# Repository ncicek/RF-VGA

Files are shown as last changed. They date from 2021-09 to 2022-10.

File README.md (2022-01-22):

# RF-VGA
A handy RF amplifier/attenuator tool for the lab. Based on a Hittite HMC625B.

- Frequency: 50MHz to 4GHz (see response plots below for roll off)
- Approximate gain / attenuation range: -10dB to +20dB
- Max input power: 11dBm
- Max output power: 16dBm (1dB compression point)

# Render:
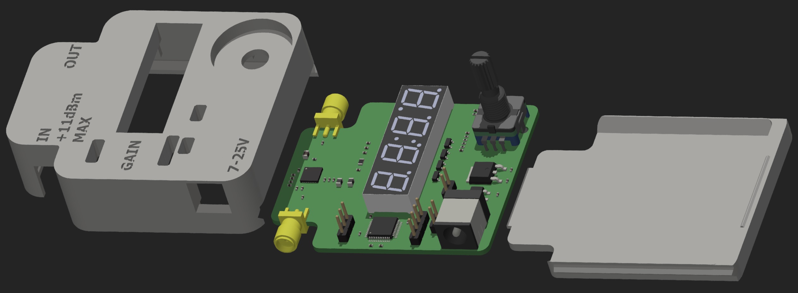
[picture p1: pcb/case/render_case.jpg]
Photo of the RF-VGA unit


# Board photo:
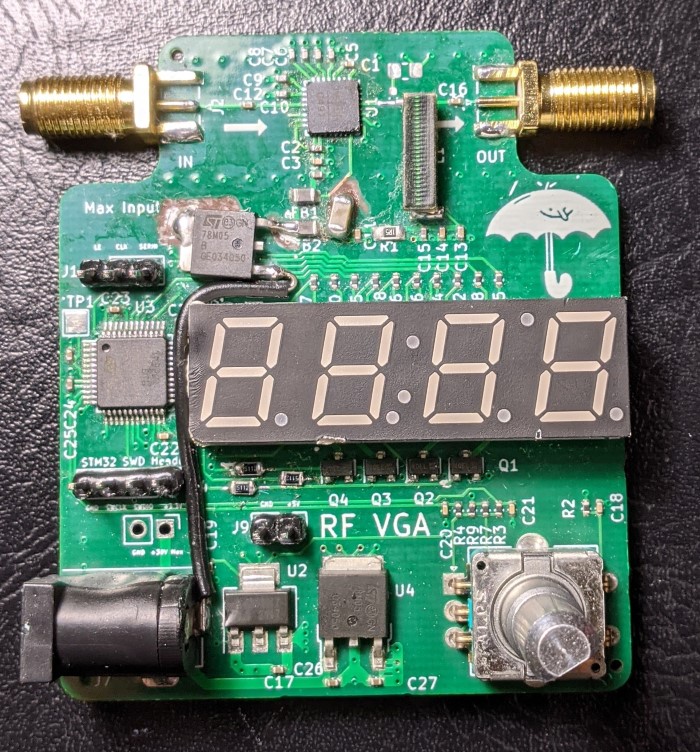
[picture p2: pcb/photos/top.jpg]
Photo of the RF-VGA board


# VNA characterization results:

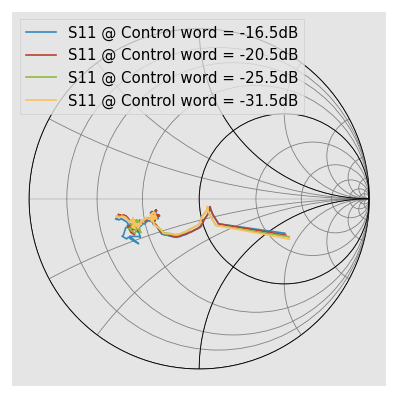
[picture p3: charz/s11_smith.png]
S11 Smith Chart


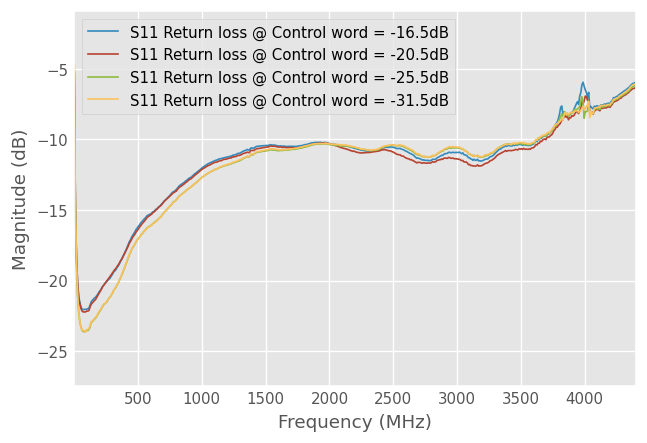
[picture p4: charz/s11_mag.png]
S11 Mag Chart

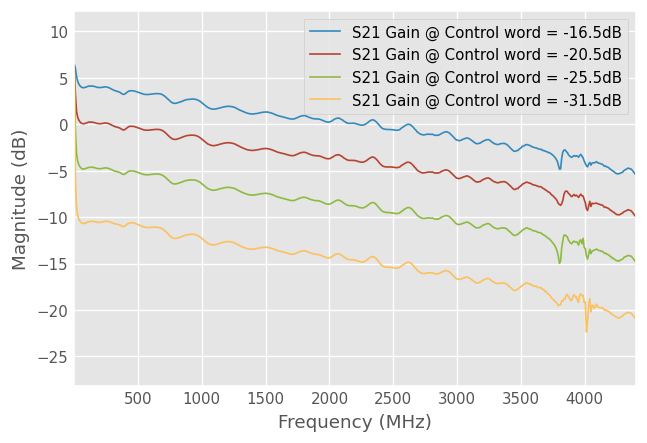
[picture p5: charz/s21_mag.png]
S21 Mag Chart


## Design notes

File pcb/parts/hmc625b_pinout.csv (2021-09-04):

HMC625B
Pin | Type | Name | Side
1 | input | AMPIN | left
29 | output | AMPOUT | right
2 | power | GND | bottom
3 | power | GND | bottom
13 | power | GND | bottom
28 | power | GND | bottom
30 | power | GND | bottom
31 | power | GND | bottom
32 | power | GND | bottom
4 | input | ATTOUT | left
12 | output | ATTIN | right
5 | input | AGC1 | bottom
6 | input | AGC2 | bottom
7 | input | AGC3 | bottom
8 | input | AGC4 | bottom
9 | input | AGC5 | bottom
10 | input | AGC6 | bottom
11 | input | GND | bottom
14 | output | SEROUT | right
15 | input | PUP2 | left
16 | input | PUP1 | left
18 | input | D5 | left
19 | input | D4 | left
20 | input | D3 | left
21 | input | D2 | left
22 | input | D1 | left
23 | input | D0 | left
24 | input | P/S | left
25 | input | CLK | left
26 | input | SERIN | left
27 | input | LE | left
17 | power | VDD | top

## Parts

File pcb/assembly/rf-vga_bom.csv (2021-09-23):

Comment | Designator | Footprint | LCSC
0.1u | C1,C12,C16,C22,C23,C24,C25,C28 | Capacitor_SMD:C_0402_1005Metric | C1525
2.2u | C13 | Capacitor_SMD:C_0402_1005Metric | C23733
0.1n | C2,C15 | Capacitor_SMD:C_0402_1005Metric | C1546
10n | C18,C20,C21 | Capacitor_SMD:C_0402_1005Metric | C15195
1n | C3,C11,C14 | Capacitor_SMD:C_0402_1005Metric | C1523
1u | C4,C17,C19,C26,C27 | Capacitor_SMD:C_0402_1005Metric | C52923
330p | C5,C6,C7,C8,C9,C10 | Capacitor_SMD:C_0402_1005Metric | C13533
TDCG1060M | DS1 | parts:DISPLAY_TDCG1060M
GZ2012D601TF | FB1,FB2 | Inductor_SMD:L_0805_2012Metric | C1017
TEST CONNECTOR | J1 | Connector_PinHeader_2.54mm:PinHeader_1x03_P2.54mm_Vertical
Input | J2 | parts:SMA_Samtec_SMA-J-P-X-ST-EM1_EdgeMount_withSTEP
Output | J3 | parts:SMA_Samtec_SMA-J-P-X-ST-EM1_EdgeMount_withSTEP
SWD Programming Header | J4 | Connector_PinHeader_2.54mm:PinHeader_1x04_P2.54mm_Vertical
Conn_02x04_Odd_Even | J5 | Connector_PinHeader_2.54mm:PinHeader_2x04_P2.54mm_Vertical
Barrel_Jack_Switch | J7 | Connector_BarrelJack:BarrelJack_Horizontal
30V input | J8 | Connector_PinHeader_2.54mm:PinHeader_1x02_P2.54mm_Vertical
5V input bypass | J9 | Connector_PinHeader_2.54mm:PinHeader_1x02_P2.54mm_Vertical
3.5u | L1 | 4310LC:4310LC
2N7002 | Q1,Q2,Q3,Q4 | Package_TO_SOT_SMD:SOT-23 | C20917
1.8 | R1 | Resistor_SMD:R_0402_1005Metric
10k | R2,R3,R4,R7,R9 | Resistor_SMD:R_0402_1005Metric | C25744
82 | R5,R6,R8,R10,R12,R14,R15,R16,R17,R18 | Resistor_SMD:R_0402_1005Metric | C25076
Rotary_Encoder_Switch | SW1 | Rotary_Encoder:RotaryEncoder_Alps_EC11E-Switch_Vertical_H20mm_CircularMountingHoles
TestPoint | TP1 | TestPoint:TestPoint_Pad_2.0x2.0mm
HMC625B | U1 | Package_DFN_QFN:QFN-32-1EP_5x5mm_P0.5mm_EP3.45x3.45mm_ThermalVias
LM1117-3.3 | U2 | Package_TO_SOT_SMD:SOT-223-3_TabPin2 | C6186
STM32L010C6 | U3 | Package_QFP:LQFP-48_7x7mm_P0.5mm | C2802165
LM78M05_TO252 | U4 | Package_TO_SOT_SMD:TO-252-2 | C58069

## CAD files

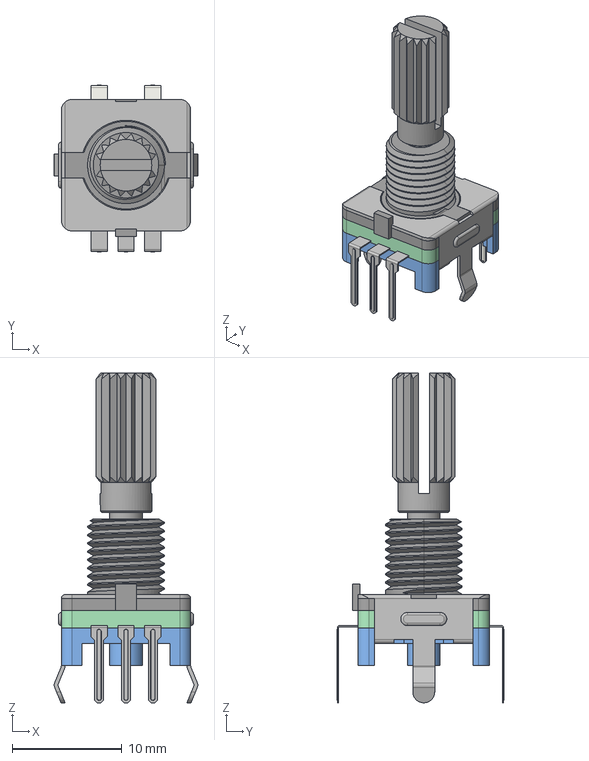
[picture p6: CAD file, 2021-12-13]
pcb/parts/EC11_Rotary_Encoder_Switched.step
13.1 x 15.3 x 30.1 mm

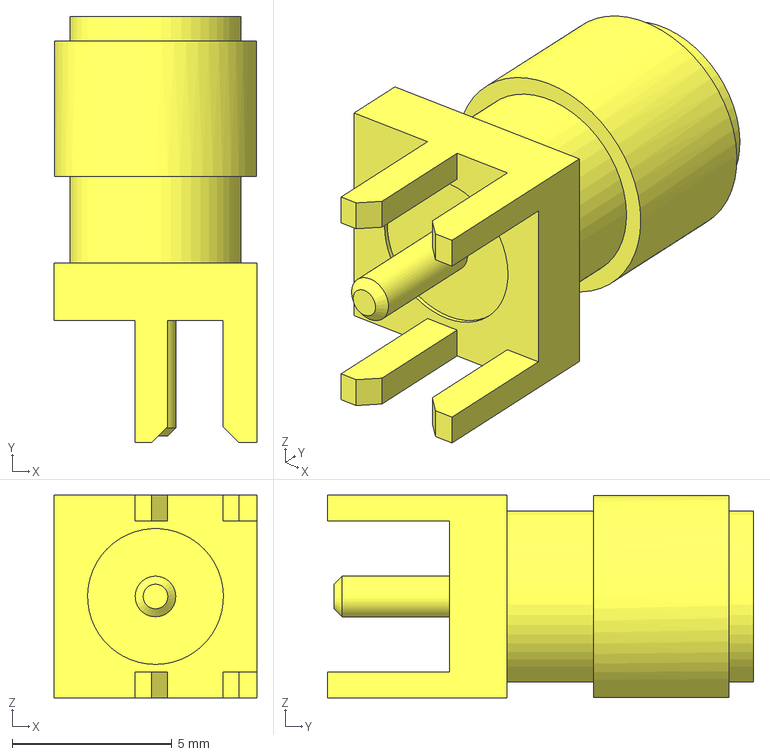
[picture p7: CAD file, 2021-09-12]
pcb/parts/SMA-J-P-H-ST-EM1--3DModel-STEP-46669.STEP
6.35 x 13.3 x 6.35 mm

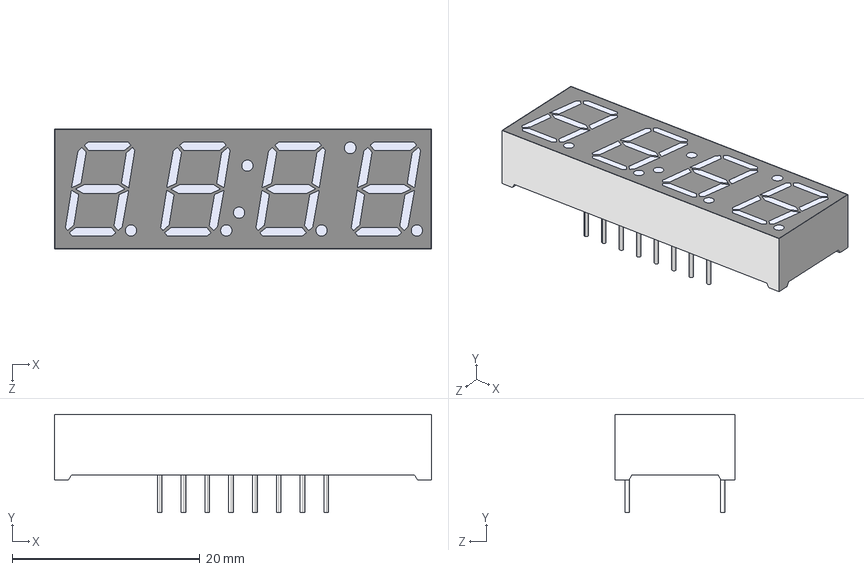
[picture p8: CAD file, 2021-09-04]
pcb/parts/TDCG1060M.step
40.2 x 10.5 x 12.8 mm

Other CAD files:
pcb/case/BarrelJack_CUI_PJ-063AH_Horizontal.iam
pcb/case/COMPOUND.ipt
pcb/case/COMPOUND_1.ipt
pcb/case/COMPOUND_2.ipt
pcb/case/COMPOUND_3.ipt
pcb/case/C_0402_1005Metric.iam
pcb/case/C_0805_2012Metric.iam
pcb/case/EC11_Rotary_Encoder_Switched.iam
pcb/case/LQFP-48_7x7mm_P0.5mm.iam
pcb/case/L_0402_1005Metric.iam
pcb/case/L_0805_2012Metric.iam
pcb/case/PinHeader_1x02_P2.54mm_Vertical.iam
pcb/case/PinHeader_1x03_P2.54mm_Vertical.iam
pcb/case/PinHeader_1x04_P2.54mm_Vertical.iam
pcb/case/PinHeader_2x04_P2.54mm_Vertical.iam
pcb/case/QFN-32-1EP_5x5mm_P0.5mm_EP3.45x3.45mm.iam
pcb/case/R_0402_1005Metric.iam
pcb/case/R_0805_2012Metric.iam
pcb/case/SMA-J-P-H-ST-EM1--3DModel-STEP-46669.iam
pcb/case/SOLID.ipt
pcb/case/SOLID_1.ipt
pcb/case/SOLID_10.ipt
pcb/case/SOLID_11.ipt
pcb/case/SOLID_12.ipt
pcb/case/SOLID_13.ipt
pcb/case/SOLID_14.ipt
pcb/case/SOLID_15.ipt
pcb/case/SOLID_2.ipt
pcb/case/SOLID_3.ipt
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

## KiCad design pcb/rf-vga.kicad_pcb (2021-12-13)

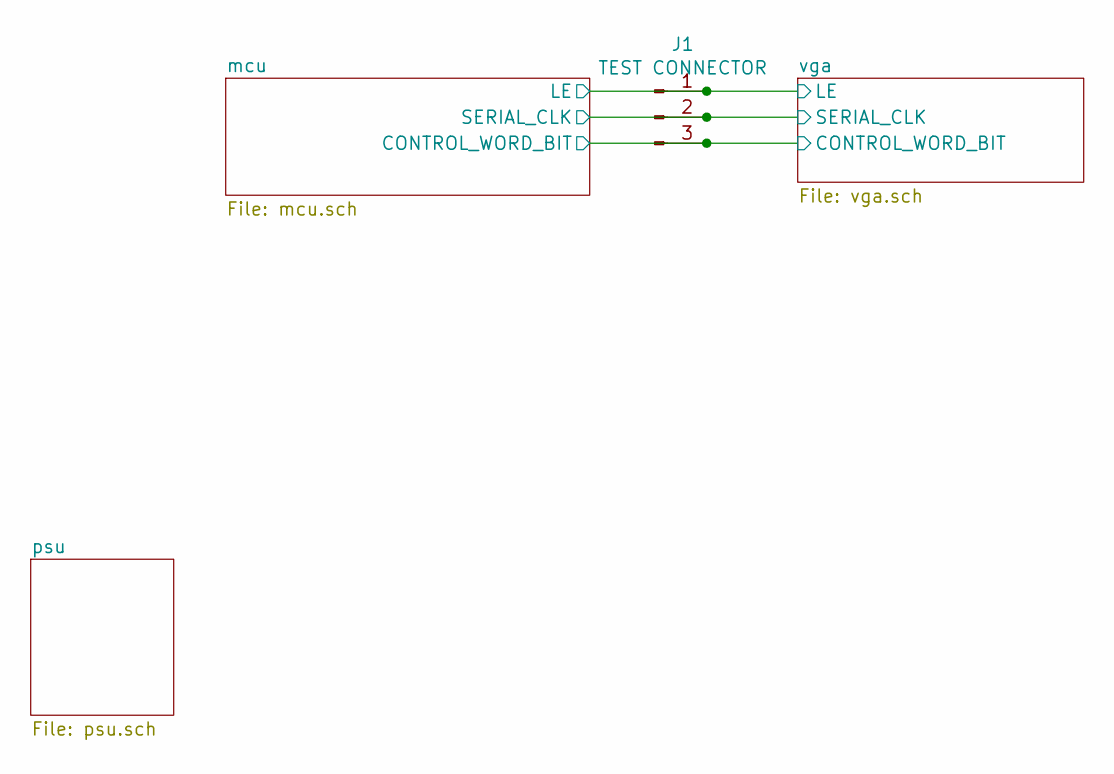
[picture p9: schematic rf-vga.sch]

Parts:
J1: TEST CONNECTOR; PinHeader_1x03_P2.54mm_Vertical

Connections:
/mcu/CONTROL_WORD_BIT: J1.3; also elsewhere on the board
/mcu/LE: J1.1; also elsewhere on the board
/mcu/SERIAL_CLK: J1.2; also elsewhere on the board

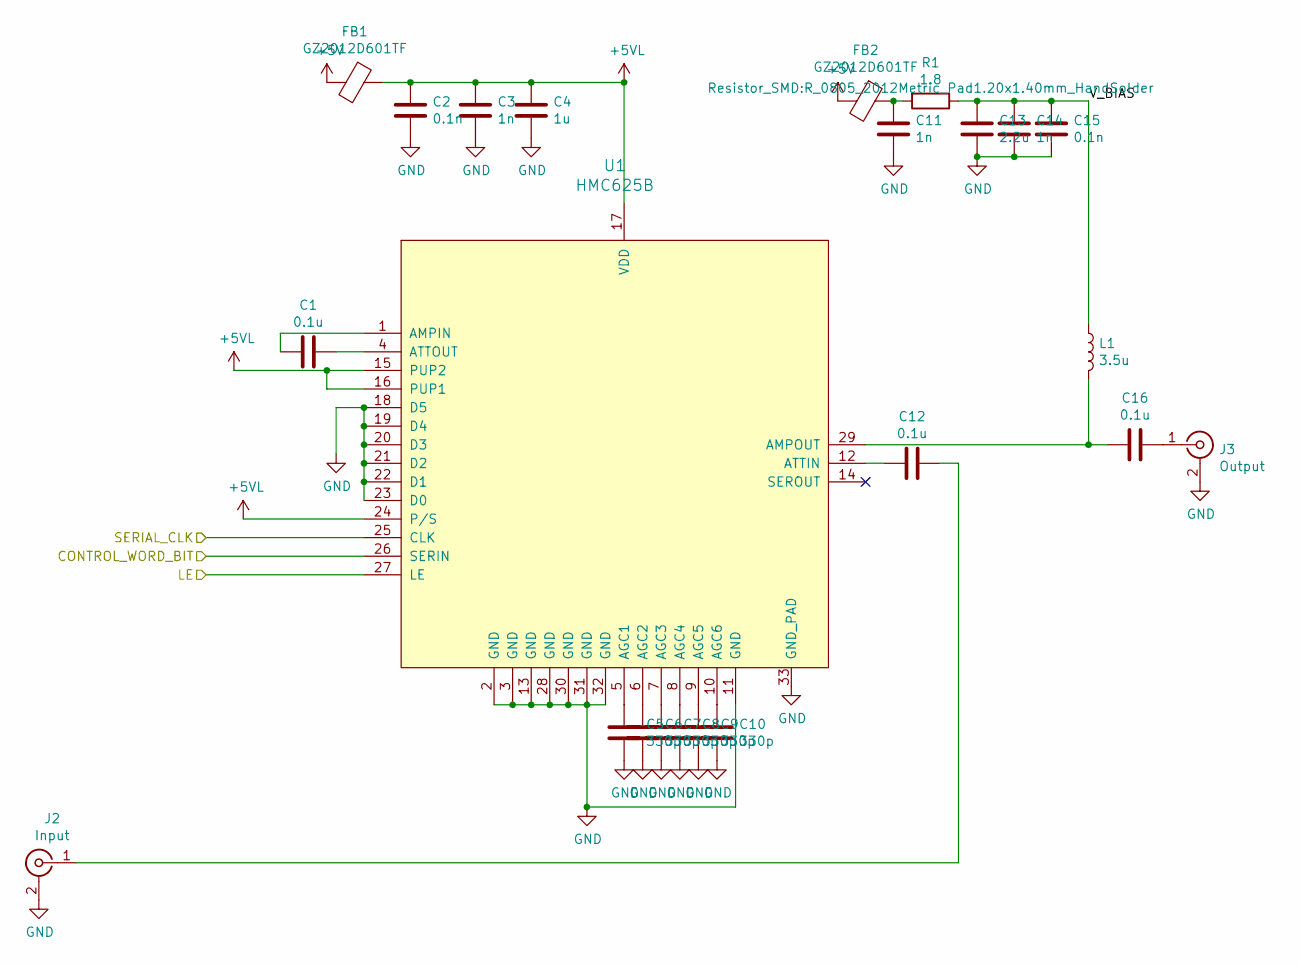
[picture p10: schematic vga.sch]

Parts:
C1, C12, C16: 0.1u; C_0402_1005Metric
C2, C15: 0.1n; C_0402_1005Metric
C3, C11, C14: 1n; C_0402_1005Metric
C4: 1u; C_0402_1005Metric
C5, C6, C7, C8, C9, C10: 330p; C_0402_1005Metric
C13: 2.2u; C_0402_1005Metric
FB1, FB2: GZ2012D601TF; L_0805_2012Metric
J2: Input; SMA_Samtec_SMA-J-P-X-ST-EM1_EdgeMount_withSTEP
J3: Output; SMA_Samtec_SMA-J-P-X-ST-EM1_EdgeMount_withSTEP
L1: 3.5u; 4310LC
R1: 1.8; R_0805_2012Metric_Pad1.20x1.40mm_HandSolder
U1: HMC625B; QFN-32-1EP_5x5mm_P0.5mm_EP3.45x3.45mm_ThermalVias

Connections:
+5V: FB1.2, FB2.2; also elsewhere on the board
+5VL: C2.1, C3.1, C4.1, FB1.1, U1.15 (PUP2), U1.16 (PUP1), U1.17 (VDD), U1.24 (P/S)
/mcu/CONTROL_WORD_BIT: U1.26 (SERIN); also elsewhere on the board
/mcu/LE: U1.27 (LE); also elsewhere on the board
/mcu/SERIAL_CLK: U1.25 (CLK); also elsewhere on the board
/vga/V_BIAS: C13.1, C14.1, C15.1, L1.1, R1.1
GND: C2.2, C3.2, C4.2, C5.2, C6.2, C7.2, C8.2, C9.2, C10.2, C11.2, C13.2, C14.2, C15.2, J2.2 (Ext), J3.2 (Ext), U1.2 (GND), U1.3 (GND), U1.11 (GND), U1.13 (GND), U1.18 (D5), U1.19 (D4), U1.20 (D3), U1.21 (D2), U1.22 (D1), U1.23 (D0), U1.28 (GND), U1.30 (GND), U1.31 (GND), U1.32 (GND), U1.33 (GND_PAD); also elsewhere on the board
unnamed: C1.1, U1.4 (ATTOUT)
unnamed: C1.2, U1.1 (AMPIN)
unnamed: C5.1, U1.5 (AGC1)
unnamed: C6.1, U1.6 (AGC2)
unnamed: C7.1, U1.7 (AGC3)
unnamed: C8.1, U1.8 (AGC4)
unnamed: C9.1, U1.9 (AGC5)
unnamed: C10.1, U1.10 (AGC6)
unnamed: C11.1, FB2.1, R1.2
unnamed: C12.1, J2.1 (In)
unnamed: C12.2, U1.12 (ATTIN)
unnamed: C16.1, J3.1 (In)
unnamed: C16.2, L1.2, U1.29 (AMPOUT)

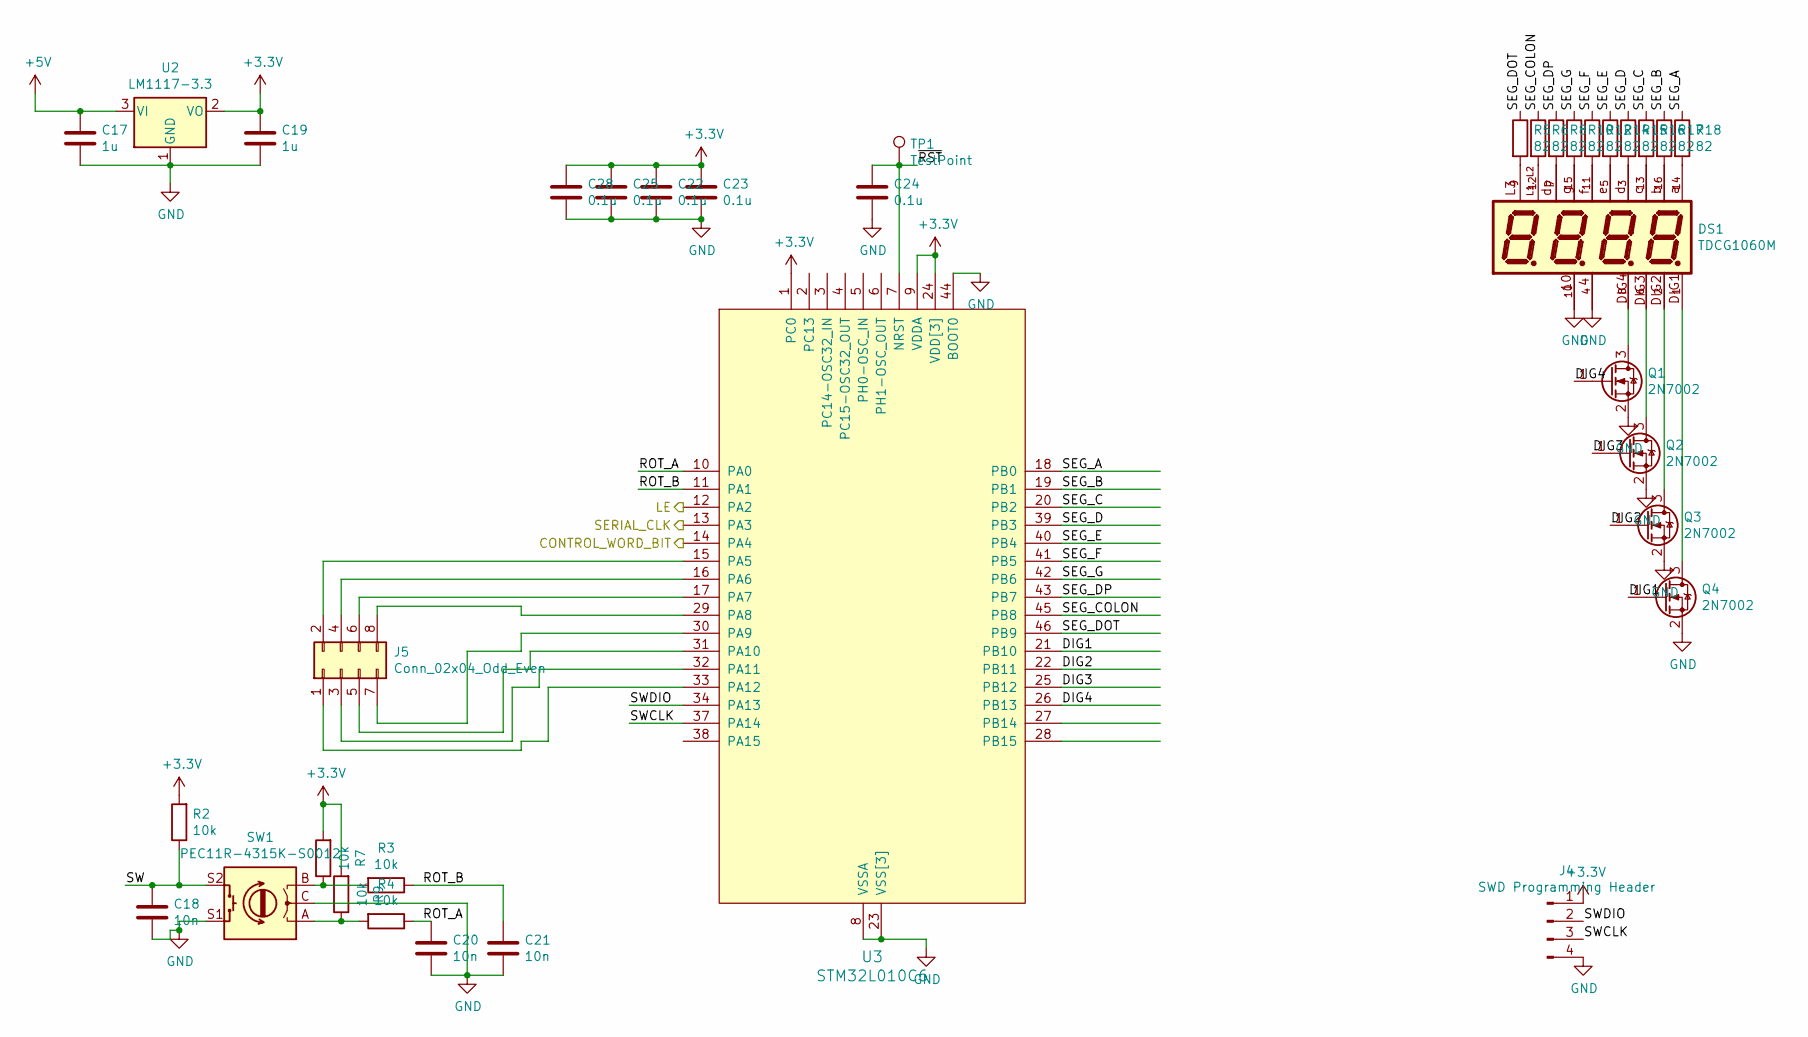
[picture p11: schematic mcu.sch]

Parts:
C17, C19: 1u; C_0402_1005Metric
C18, C20, C21: 10n; C_0402_1005Metric
C22, C23, C24, C25, C28: 0.1u; C_0402_1005Metric
DS1: TDCG1060M; DISPLAY_TDCG1060M; PARTREV 1.7
J4: SWD Programming Header; PinHeader_1x04_P2.54mm_Vertical
J5: Conn_02x04_Odd_Even; PinHeader_2x04_P2.54mm_Vertical
Q1, Q2, Q3, Q4: 2N7002; SOT-23
R2, R3, R4, R7, R9: 10k; R_0402_1005Metric
R5, R6, R8, R10, R12, R14, R15, R16, R17, R18: 82; R_0402_1005Metric
SW1: PEC11R-4315K-S0012; RotaryEncoder_Alps_EC11E-Switch_Vertical_H20mm_CircularMoun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
TP1: TestPoint; TestPoint_Pad_2.0x2.0mm
U2: LM1117-3.3; SOT-223-3_TabPin2
U3:  STM32L010C6; LQFP-48_7x7mm_P0.5mm

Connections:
+3V3: C19.1, C22.1, C23.1, C25.1, C28.1, J4.1, R2.2, R7.2, R9.2, U2.2 (VO), U3.1 (PC0), U3.9 (VDDA), U3.24 (VDD[3]), U3.36 (VDD[3]), U3.48 (VDD[3])
+5V: C17.1, U2.3 (VI); also elsewhere on the board
/mcu/CONTROL_WORD_BIT: U3.14 (PA4); also elsewhere on the board
/mcu/DIG1: Q4.1 (G), U3.21 (PB10)
/mcu/DIG2: Q3.1 (G), U3.22 (PB11)
/mcu/DIG3: Q2.1 (G), U3.25 (PB12)
/mcu/DIG4: Q1.1 (G), U3.26 (PB13)
/mcu/LE: U3.12 (PA2); also elsewhere on the board
/mcu/ROT_A: C20.1, R4.1, U3.10 (PA0)
/mcu/ROT_B: C21.1, R3.1, U3.11 (PA1)
/mcu/SEG_A: R18.1, U3.18 (PB0)
/mcu/SEG_B: R17.1, U3.19 (PB1)
/mcu/SEG_C: R16.1, U3.20 (PB2)
/mcu/SEG_COLON: R6.1, U3.45 (PB8)
/mcu/SEG_D: R15.1, U3.39 (PB3)
/mcu/SEG_DOT: R5.1, U3.46 (PB9)
/mcu/SEG_DP: R8.1, U3.43 (PB7)
/mcu/SEG_E: R14.1, U3.40 (PB4)
/mcu/SEG_F: R12.1, U3.41 (PB5)
/mcu/SEG_G: R10.1, U3.42 (PB6)
/mcu/SERIAL_CLK: U3.13 (PA3); also elsewhere on the board
/mcu/SW: C18.1, R2.1, SW1.S2
/mcu/SWCLK: J4.3, U3.37 (PA14)
/mcu/SWDIO: J4.2, U3.34 (PA13)
/mcu/~RST: C24.1, TP1.1, U3.7 (NRST)
GND: C17.2, C18.2, C19.2, C20.2, C21.2, C22.2, C23.2, C24.2, C25.2, C28.2, DS1.4, DS1.10, J4.4, Q1.2 (S), Q2.2 (S), Q3.2 (S), Q4.2 (S), SW1.C, SW1.S1, U2.1 (GND), U3.8 (VSSA), U3.23 (VSS[3]), U3.35 (VSS[3]), U3.44 (BOOT0), U3.47 (VSS[3]); also elsewhere on the board
unnamed: DS1.1, Q4.3 (D)
unnamed: DS1.2, Q3.3 (D)
unnamed: DS1.3, R15.2
unnamed: DS1.5, R14.2
unnamed: DS1.6, Q2.3 (D)
unnamed: DS1.7, R8.2
unnamed: DS1.8, Q1.3 (D)
unnamed: DS1.9, R5.2
unnamed: DS1.11, R12.2
unnamed: DS1.12, R6.2
unnamed: DS1.13, R16.2
unnamed: DS1.14, R18.2
unnamed: DS1.15, R10.2
unnamed: DS1.16, R17.2
unnamed: J5.1, U3.33 (PA12)
unnamed: J5.2, U3.15 (PA5)
unnamed: J5.3, U3.32 (PA11)
unnamed: J5.4, U3.16 (PA6)
unnamed: J5.5, U3.31 (PA10)
unnamed: J5.6, U3.17 (PA7)
unnamed: J5.7, U3.30 (PA9)
unnamed: J5.8, U3.29 (PA8)
unnamed: R3.2, R7.1, SW1.B
unnamed: R4.2, R9.1, SW1.A

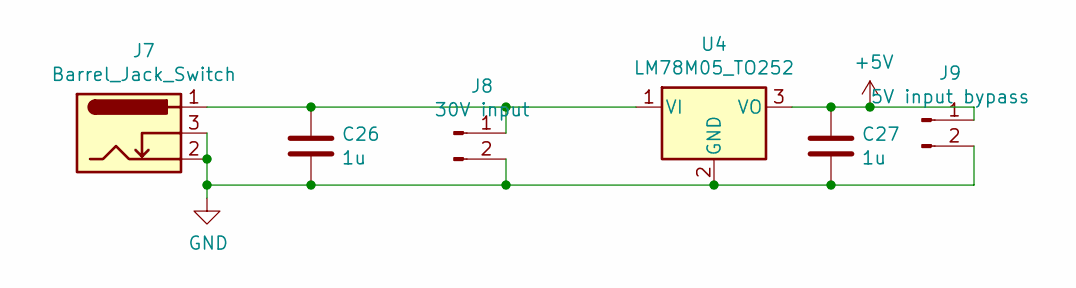
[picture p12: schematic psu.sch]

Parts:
C26, C27: 1u; C_0402_1005Metric
J7: Barrel_Jack_Switch; BarrelJack_Horizontal
J8: 30V input; PinHeader_1x02_P2.54mm_Vertical
J9: 5V input bypass; PinHeader_1x02_P2.54mm_Vertical
U4: LM78M05_TO252; TO-252-2

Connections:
+5V: C27.1, J9.1, U4.3 (VO); also elsewhere on the board
GND: C26.2, C27.2, J7.2, J7.3, J8.2, J9.2, U4.2 (GND); also elsewhere on the board
unnamed: C26.1, J7.1, J8.1, U4.1 (VI)

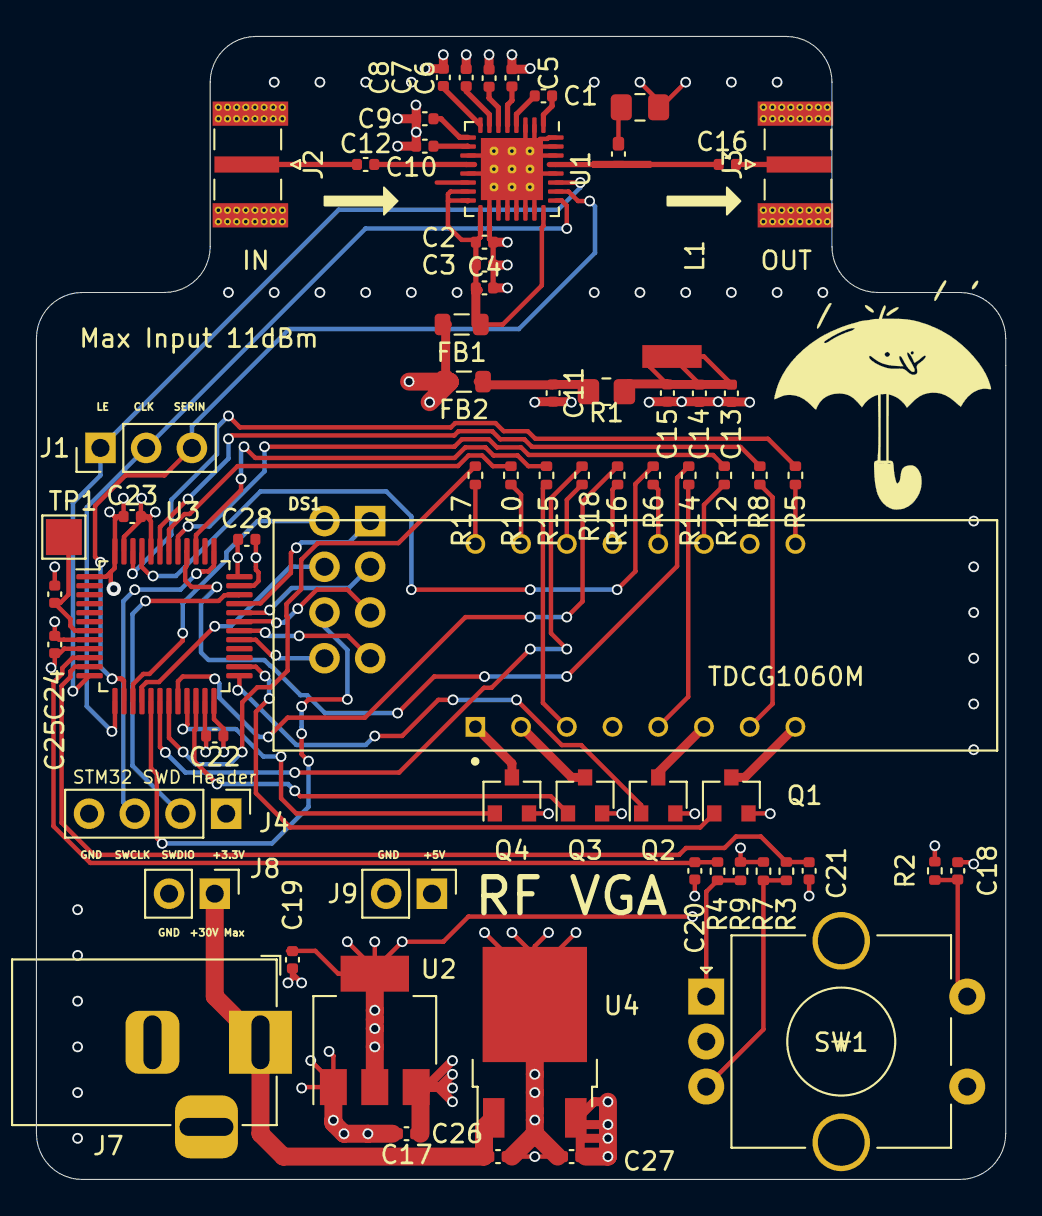
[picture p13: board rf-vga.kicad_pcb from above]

Board: 4 copper layers, 53.8 x 63.5 mm, 66 parts (1 on the bottom side), 66 nets.

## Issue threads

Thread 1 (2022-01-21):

LED switching noise on output

ncicek, 2022-01-21:
The seven segment display multiplexing is found to create lots of switching noise on the RF output.
The stm32 runs the seven segment on 3.3V rail and causes di/dt when digit FETs are switched on/off. This noise couples upstream into the 5V regulator's output and leaks into the Vbias of the amplifier.

Two things were needed to eliminate this on the first revision:
- Add series resistor to the 4 FET gates to reduce slew rate (47k worked well - reduces gate slew from 200ns -> 200us)
- Add dedicated 5V regulator to power the Hittite chip

Additional improvement ideas:
- Add bulk cap on input supply
- Add more cap to Vbias
- Add stitiching vias in between Vbias rail and segment lines to reduce any chance of inductive coupling.

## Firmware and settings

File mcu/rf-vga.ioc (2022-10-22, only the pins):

Mcu.UserName=STM32L051C8Tx
PA0.Signal=S_TIM2_CH1
PA1.Signal=S_TIM2_CH2
PA13.Signal=SYS_SWDIO
PA14.Signal=SYS_SWCLK
PA2.GPIO_Label=LE
PA2.Signal=GPIO_Output
PA3.GPIO_Label=SER_CLK
PA3.Signal=GPIO_Output
PA4.GPIO_Label=SER_OUT
PA4.Signal=GPIO_Output
PB0.Signal=GPIO_Output
PB1.Signal=GPIO_Output
PB10.Signal=GPIO_Output
PB11.Signal=GPIO_Output
PB12.Signal=GPIO_Output
PB13.Signal=GPIO_Output
PB2.Signal=GPIO_Output
PB3.Signal=GPIO_Output
PB4.Signal=GPIO_Output
PB5.Signal=GPIO_Output
PB6.Signal=GPIO_Output
PB7.Signal=GPIO_Output
PB8.Signal=GPIO_Output
PB9.Signal=GPIO_Output

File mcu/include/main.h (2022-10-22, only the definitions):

#define LE_Pin GPIO_PIN_2
#define LE_GPIO_Port GPIOA
#define SER_CLK_Pin GPIO_PIN_3
#define SER_CLK_GPIO_Port GPIOA
#define SER_OUT_Pin GPIO_PIN_4
#define SER_OUT_GPIO_Port GPIOA

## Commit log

2021-09-04 Add STM32L010C6 mcu to pcb, allocate pins
    [TDCG1060M.step, mcu.sch, rf-vga.kicad_pcb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]
2021-09-04 remove csv from git ignore, add kipart source
    [hmc625b_pinout.csv]
2021-09-04 Add STM32 kipart source
    [STM32L010C6.csv]
2021-09-12 PCB updates
    [SMA-J-P-H-ST-EM1--3DModel-STEP-46669.STEP, mcu.sch, psu.sch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]
2021-09-14 layout check in
    [mcu.sch, psu.sch, rf-vga.kicad_pcb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]
2021-09-16 Completed PCB layout
    [mcu.sch, rf-vga.kicad_pcb, vga.sch]
2021-09-23 final tweaks and produce outputs for jlcpcb fabrication
    [mcu.sch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]
2021-10-21 Enable encoder input
    [rf-vga Debug.cfg]
2021-12-13 Made a 3d printed case
    [BarrelJack_CUI_PJ-063AH_Horizontal.iam, COMPOUND.ipt, COMPOUND_1.ipt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]
2022-01-20 Fix seven seg display issues
    [rf-vga.c, seven_seg.c]
2022-01-20 Enclosure updates
    [case_assembly.iam]
2022-01-21 Reduce di/dt due to seven segment switching
2022-01-21 Update seven segment timers for reduced di/dt
2022-01-22 Startup at lowest output power
2022-10-22 Move firmware to platformio
    [rf-vga Debug.cfg]

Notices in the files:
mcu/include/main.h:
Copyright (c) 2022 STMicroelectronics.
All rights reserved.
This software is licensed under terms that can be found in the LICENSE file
